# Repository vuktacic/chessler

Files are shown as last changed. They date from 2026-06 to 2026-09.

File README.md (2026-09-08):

# chessler/chessbot
A robot that plays chess. It uses a camera to detect Aruco tags on the board corners and the pieces, and an electromagnet on a gantry under the board to move the pieces. Designed for Hack Club's Outpost program. I wanted to do something involving Aruco tags outside of FRC, and this seemed like a good project to make.

## Structure
- [./assets](./assets): Repo images
- [./cad](./cad): 3d models
- [./core](./core): esp32 firmware
- [./pcb](./pcb): Kicad design files.
- [./vision](./vision): Computer side vision code
- [./bom.csv](./bom.csv): Bill of materials
- [./po.csv](./po.csv): Purchase order
- [./JOURNAL.md](./JOURNAL.md): Project journal

View the PCB on KiCanvas:  


## CAD





## Schematic

Schematic

## PCB
PCB front
PCB back
PCB assembly
PCB detail

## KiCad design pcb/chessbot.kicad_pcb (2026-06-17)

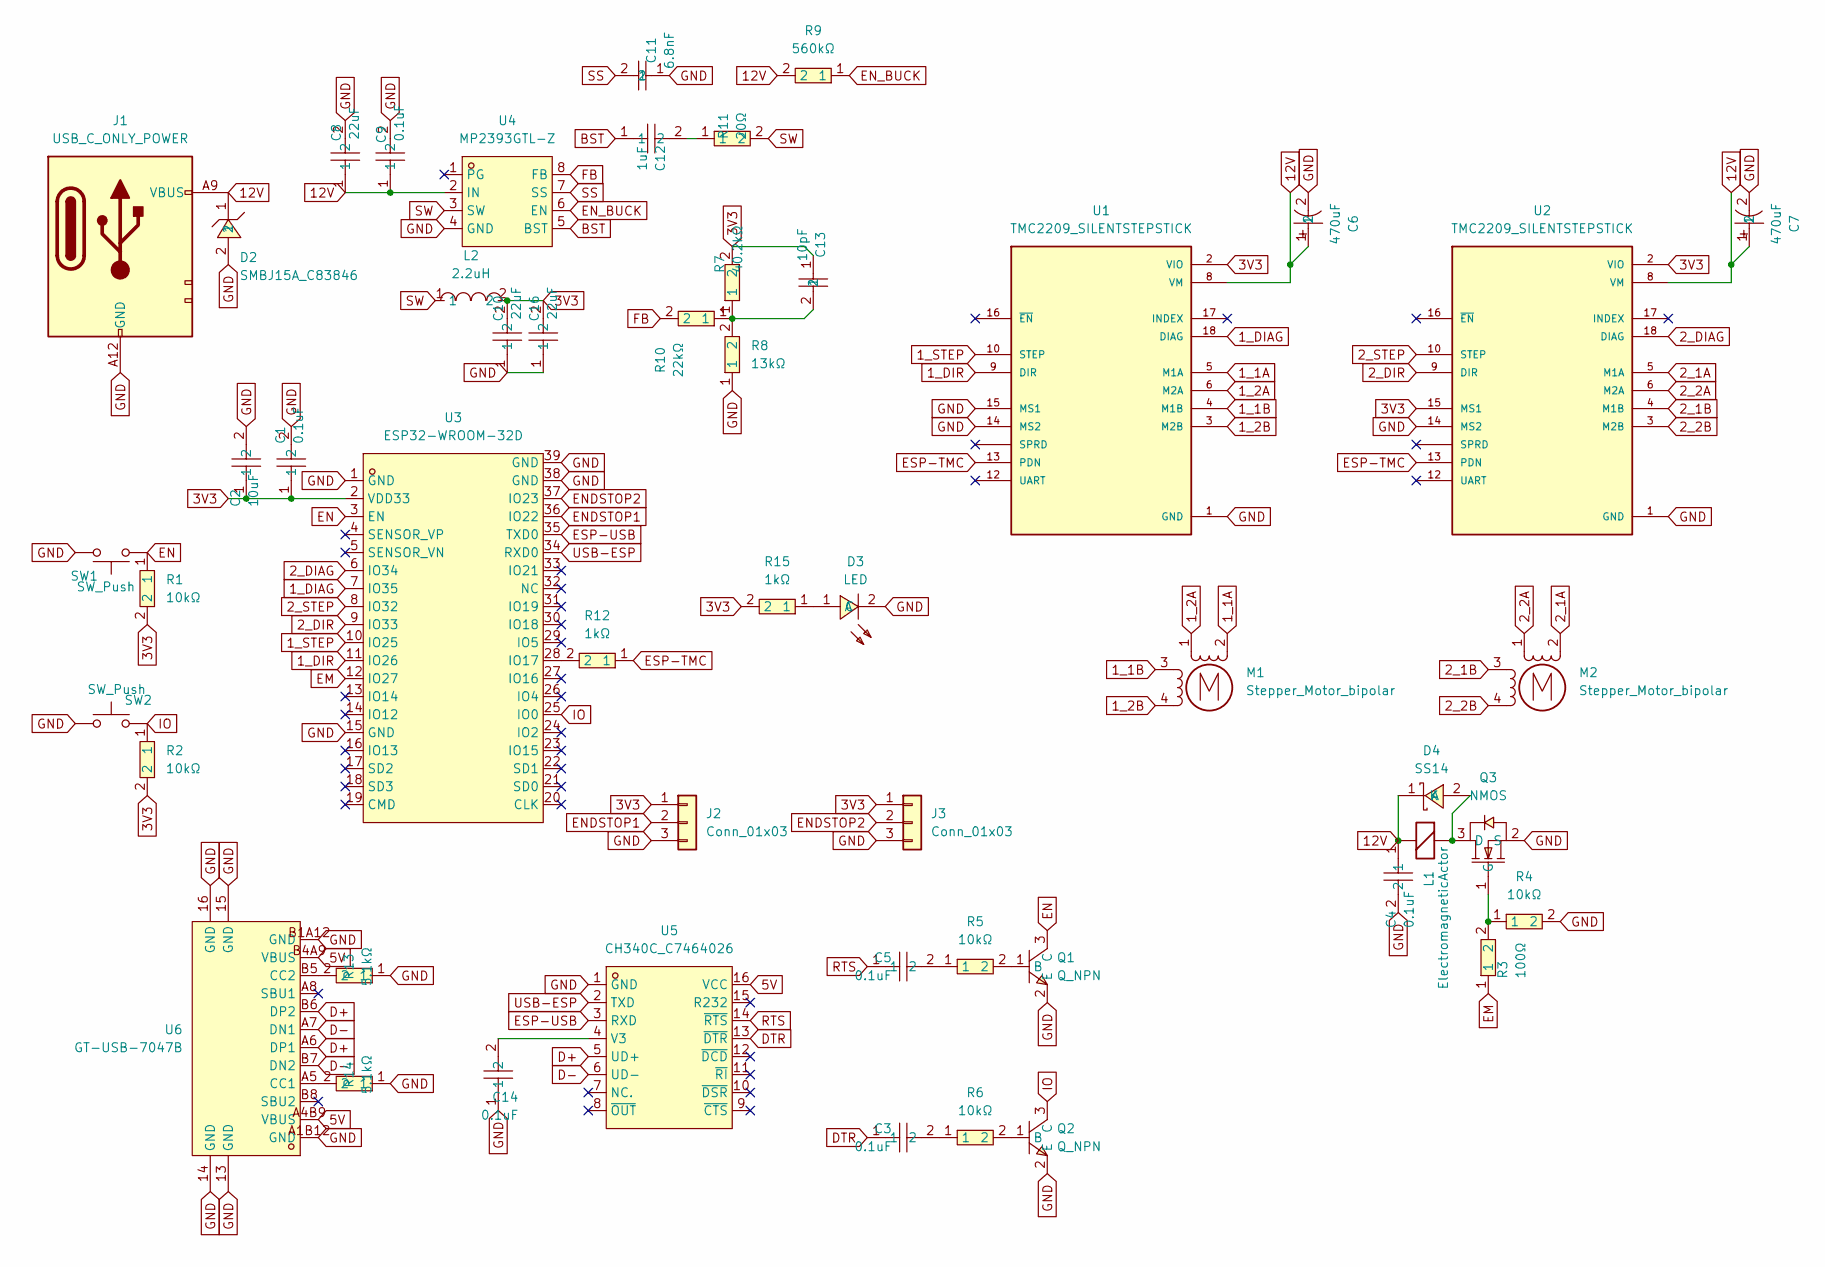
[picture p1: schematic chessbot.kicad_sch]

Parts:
C1, C3, C4, C5, C9, C14: 0.1uF; C0603; MPN CC0603KRX7R9BB104; LCSC Part C14663
C2: 10uF; C0603; MPN CL10A106MA8NRNC; LCSC Part C96446
C6, C7: 470uF; CAP-SMD_BD10.0-L10.3-W10.3-FD; MPN RVT1V471M1010; LCSC Part C3350
C8, C10, C16: 22uF; C0805; MPN CL21A226MAQNNNE; LCSC Part C45783
C11: 6.8nF; C0603; MPN 0603B682K500NT; LCSC Part C1631
C12: 1uF; C0603; MPN CL10A105KB8NNNC; LCSC Part C15849
C13: 10pF; C0603; MPN CL10C100JB8NNNC; LCSC Part C1634
D2: SMBJ15A_C83846; SMB_L4.6-W3.6-LS5.3-RD; LCSC Part C83846
D3: LED; LED0603-R-RD_AMBER; MPN BL-HJC36G-AV-TRB; LCSC Part C165983
D4: SS14; SMA_L4.2-W2.6-LS5.0-RD_1; MPN SS14; LCSC Part C2480
J1: USB_C_ONLY_POWER; USB_C_PD_BOARD
J2, J3: Conn_01x03; JST_PH_B3B-PH-K_1x03_P2.00mm_Vertical
L1: ElectromagneticActor; JST_PH_B2B-PH-K_1x02_P2.00mm_Vertical
L2: 2.2uH; L0805; MPN CMI201209U2R2KT; LCSC Part C1043
M1, M2: Stepper_Motor_bipolar; JST_PH_B4B-PH-K_1x04_P2.00mm_Vertical
Q1, Q2: Q_NPN; SOT-23-3_L2.9-W1.3-P1.90-LS2.4-BR; MPN MMBT3904(RANGE:100-300); LCSC Part C20526
Q3: NMOS; SOT-23-3_L2.9-W1.3-P1.90-LS2.4-BR; MPN AO3400A; LCSC Part C20917
R1, R2, R4, R5, R6: 10kΩ; R0805; MPN 0805W8F1002T5E; LCSC Part C17414
R3: 100Ω; R0603; MPN 0603WAF1000T5E; LCSC Part C22775
R7: 40.2kΩ; R0603; MPN 0603WAF4022T5E; LCSC Part C12447
R8: 13kΩ; R0603; MPN 0603WAF1302T5E; LCSC Part C22797
R9: 560kΩ; R0603; MPN 0603WAF5603T5E; LCSC Part C23203
R10: 22kΩ; R0603; MPN 0603WAF2202T5E; LCSC Part C31850
R11: 20Ω; R0603; MPN 0603WAF200JT5E; LCSC Part C22950
R12, R15: 1kΩ; R0603; MPN 0603WAF1001T5E; LCSC Part C21190
R13, R14: 5.1kΩ; R0603; MPN 0603WAF5101T5E; LCSC Part C23186
SW1, SW2: SW_Push; SW_PUSH_6mm
U1, U2: TMC2209_SILENTSTEPSTICK; MODULE_TMC2209_SILENTSTEPSTICK_INTERNAL SILKSCREEN; PARTREV 1.20
U3: ESP32-WROOM-32D; WIFIM-SMD_39P-L25.5-W18.0-P1.27-BL; MPN ESP32-WROOM-32D-N4; LCSC Part C529578
U4: MP2393GTL-Z; SOT-583-8_L2.1-W1.2-P0.50-LS1.6-BL; MPN MP2393GTL-Z; LCSC Part C6674609
U5: CH340C_C7464026; SOP-16_L10.0-W3.9-P1.27-LS6.0-BL; MPN CH340C; LCSC Part C7464026
U6: GT-USB-7047B; MICRO-USB-SMD_GT-USB-7047B; MPN GT-USB-7047B; LCSC Part C963217

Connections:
1_1A: M1.2 (-_2), U1.5 (M1A)
1_1B: M1.3, U1.4 (M1B)
1_2A: M1.1, U1.6 (M2A)
1_2B: M1.4, U1.3 (M2B)
1_DIAG: U1.18 (DIAG), U3.7 (IO35)
1_DIR: U1.9 (DIR), U3.11 (IO26)
1_STEP: U1.10 (STEP), U3.10 (IO25)
2_1A: M2.2 (-_2), U2.5 (M1A)
2_1B: M2.3, U2.4 (M1B)
2_2A: M2.1, U2.6 (M2A)
2_2B: M2.4, U2.3 (M2B)
2_DIAG: U2.18 (DIAG), U3.6 (IO34)
2_DIR: U2.9 (DIR), U3.9 (IO33)
2_STEP: U2.10 (STEP), U3.8 (IO32)
3V3: C1.1, C2.1, C10.2, C13.1, C16.2, J2.1, J3.1, L2.2, R1.2, R2.2, R7.2, R15.2, U1.2 (VIO), U2.2 (VIO), U2.15 (MS1), U3.2 (VDD33)
5V: U5.16 (VCC), U6.A4B9 (VBUS), U6.B4A9 (VBUS)
12V: C4.1, C6.1, C7.1, C8.1, C9.1, D2.1, D4.1 (K), J1.A9 (VBUS), L1.2 (+), R9.2, U1.8 (VM), U2.8 (VM), U4.2 (IN)
BST: C12.1, U4.5 (BST)
D+: U5.5 (UD+), U6.A6 (DP1), U6.B6 (DP2)
D-: U5.6 (UD-), U6.A7 (DN1), U6.B7 (DN2)
DTR: C3.1, U5.13 (~DTR)
EM: R3.1, U3.12 (IO27)
EN: Q1.3 (C), R1.1, SW1.1, U3.3 (EN)
ENDSTOP1: J2.2, U3.36 (IO22)
ENDSTOP2: J3.2, U3.37 (IO23)
EN_BUCK: R9.1, U4.6 (EN)
EN_TMC: U1.16 (~EN), U2.16 (~EN)
ESP-TMC: R12.1, U1.13 (PDN), U2.13 (PDN)
ESP-USB: U3.35 (TXD0), U5.3 (RXD)
FB: R10.2, U4.8 (FB)
GND: C1.2, C2.2, C4.2, C6.2, C7.2, C8.2, C9.2, C10.1, C11.1, C14.1, C16.1, D2.2, D3.2 (C), J1.A12 (GND), J2.3, J3.3, Q1.2 (E), Q2.2 (E), Q3.2 (S), R4.2, R8.1, R13.1, R14.1, SW1.2, SW2.1, U1.1 (GND), U1.7 (GND), U1.14 (MS2), U1.15 (MS1), U2.1 (GND), U2.7 (GND), U2.14 (MS2), U3.1 (GND), U3.15 (GND), U3.38 (GND), U3.39 (GND), U4.4 (GND), U5.1 (GND), U6.13 (GND), U6.14 (GND), U6.15 (GND), U6.16 (GND), U6.A1B12 (GND), U6.B1A12 (GND)
IO: Q2.3 (C), R2.1, SW2.2, U3.25 (IO0)
unnamed: C3.2, R6.1
unnamed: C5.2, R5.1
unnamed: C12.2, R11.1
unnamed: C13.2, R7.1, R8.2, R10.1
unnamed: D3.1 (A), R15.1
unnamed: D4.2 (A), L1.1 (-), Q3.3 (D)
unnamed: Q1.1 (B), R5.2
unnamed: Q2.1 (B), R6.2
unnamed: Q3.1 (G), R3.2, R4.1
unnamed: R12.2, U3.28 (IO17)
unnamed: C14.2, U5.4 (V3)
unnamed: R14.2, U6.A5 (CC1)
unnamed: R13.2, U6.B5 (CC2)
RTS: C5.1, U5.14 (~RTS)
SS: C11.2, U4.7 (SS)
SW: L2.1, R11.2, U4.3 (SW)
USB-ESP: U3.34 (RXD0), U5.2 (TXD)

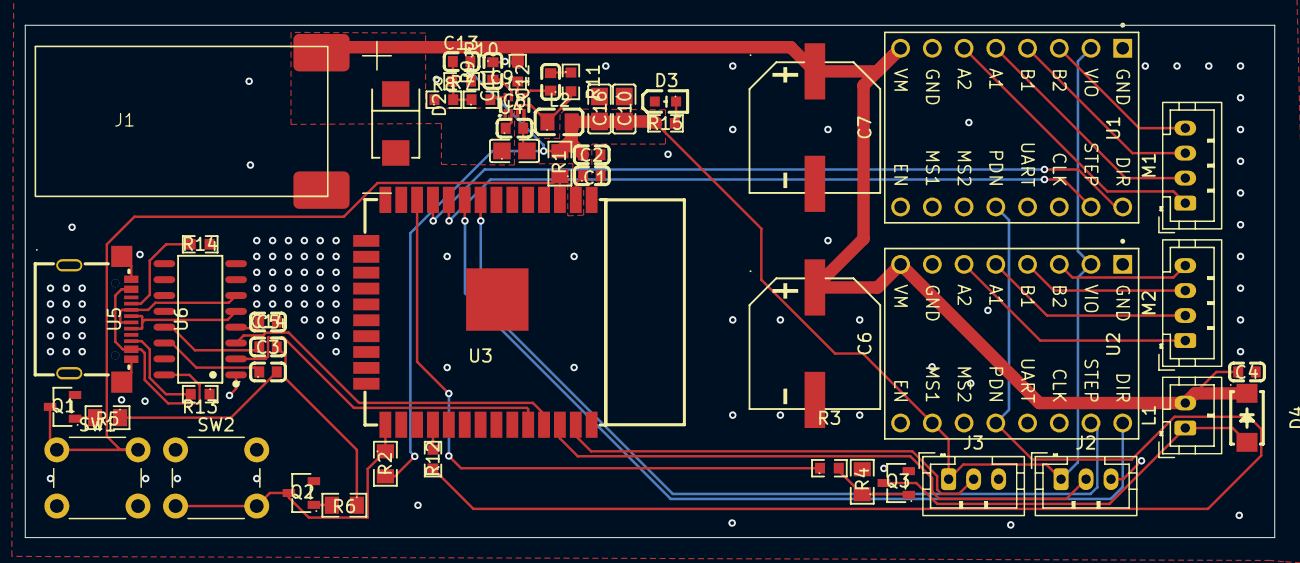
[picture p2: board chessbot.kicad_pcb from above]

Board: 2 copper layers, 100.0 x 41.0 mm, 51 parts (0 on the bottom side), 47 nets.

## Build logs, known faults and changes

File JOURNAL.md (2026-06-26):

# chessler Journal

## June 13th, 2026
New project time!
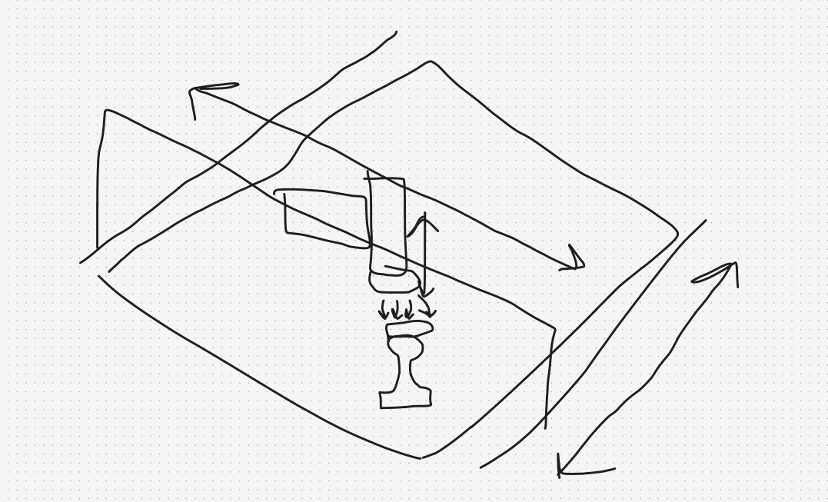
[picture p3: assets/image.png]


I've been thinking about this one for a couple days. It's a chess playing robot. My original idea was to have a gantry, but after deliberation I realized that an under the board design would be more compact, cleaner, and cheaper.

I would use a camera to detect the pieces. Object detection can be quite hard, but I realized that I can just attach pieces of coloured paper to the tops of the pieces, and then just use colour detection to find the pieces.

I started sourcing parts from aliexpress.
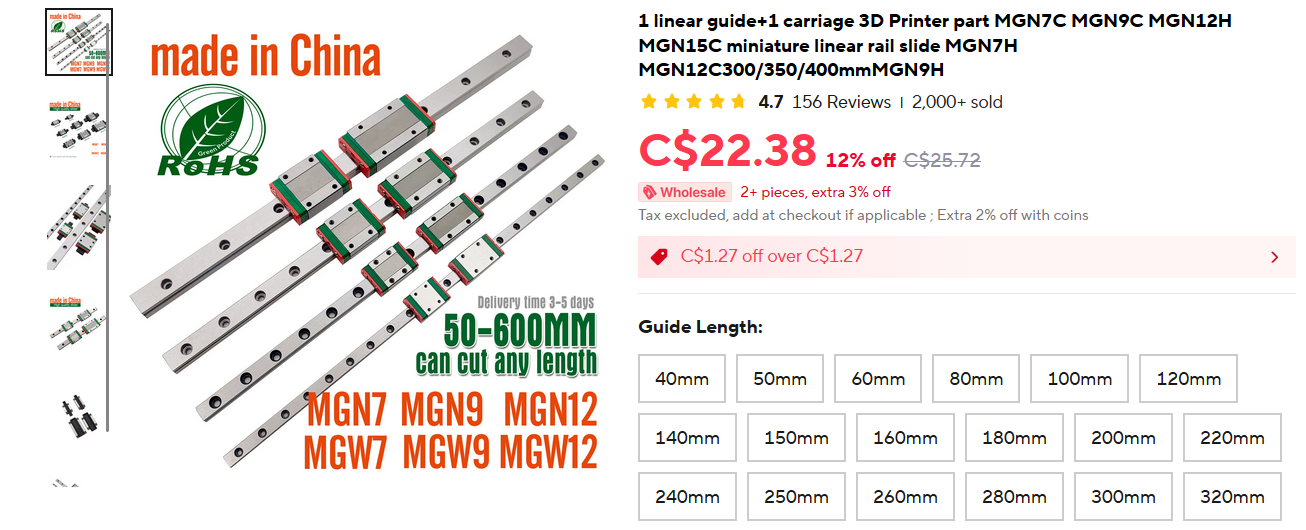
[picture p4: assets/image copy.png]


I'm using MGN12 rails, which use M3 hardware which I already have.

I also found a nice tiny electromagnet:
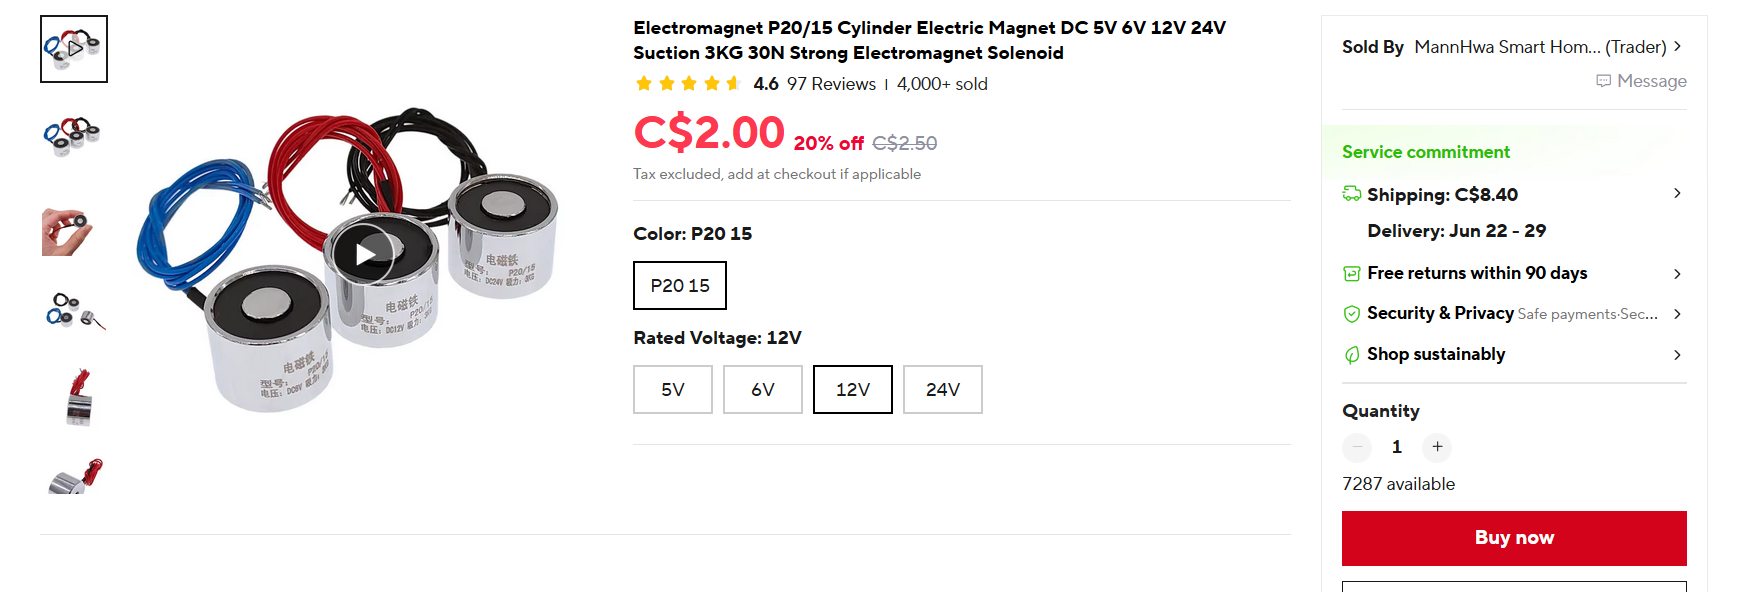
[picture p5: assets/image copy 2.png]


It's 20mm wide and 15mm thick with 30N of holding force.

About the magnet, I needed to make sure that it would be strong enough to drag pieces, but not so strong that it would pick up pieces unintendedly. (Picking up *A* piece is way easier than picking up *ONE* piece). I did some back of the napkin calculations and found that magnetic force generally dissipiates by 1/r^4. Meaning that the force of the electromagnet on side pieces is <1% of the force of a centered piece. (Assuming 6mm thick MDF and 45mm center to center piece distance).

I picked up some other things, like a bigger Nema 17 motor, M3 t-nuts, M5 brackets, extrusion, and optical endstops.
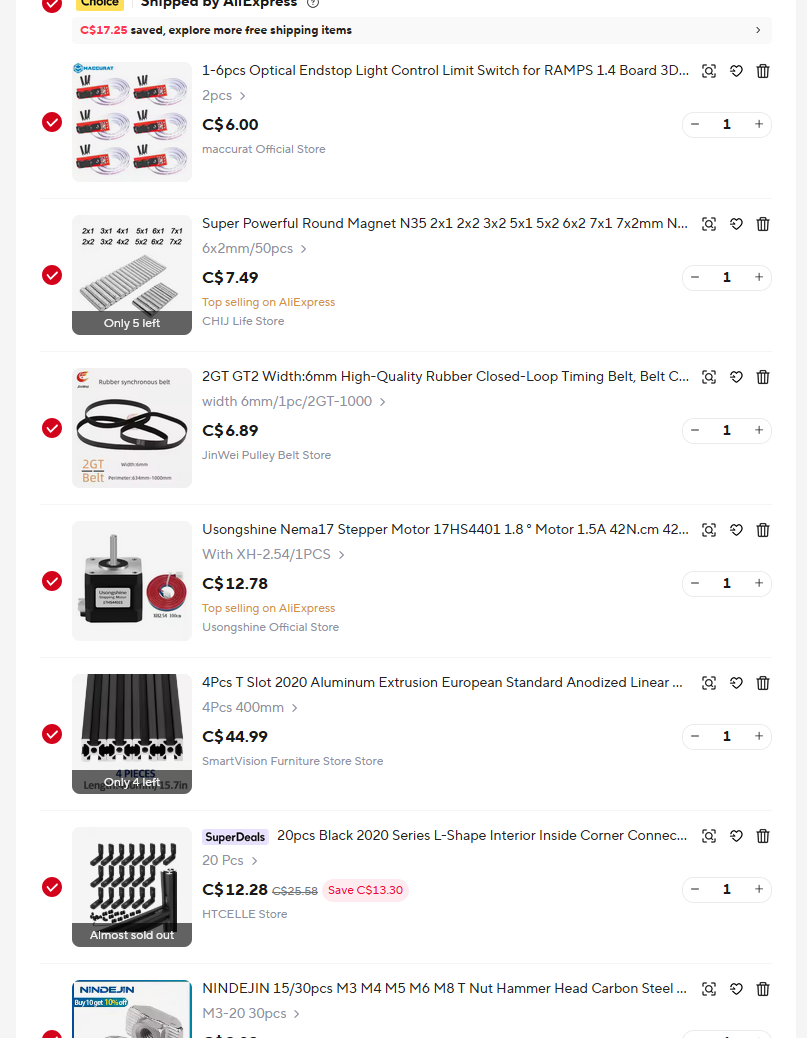
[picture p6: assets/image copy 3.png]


I then hopped into fusion and started designing this.

Funny thing, I actually have quite a lot of experience designing with Aluminum extrusion. I did it all the time for FRC, and man I hated it. I really thought I escaped it!

However, when you can actually source proper components for it, it's pretty nice!

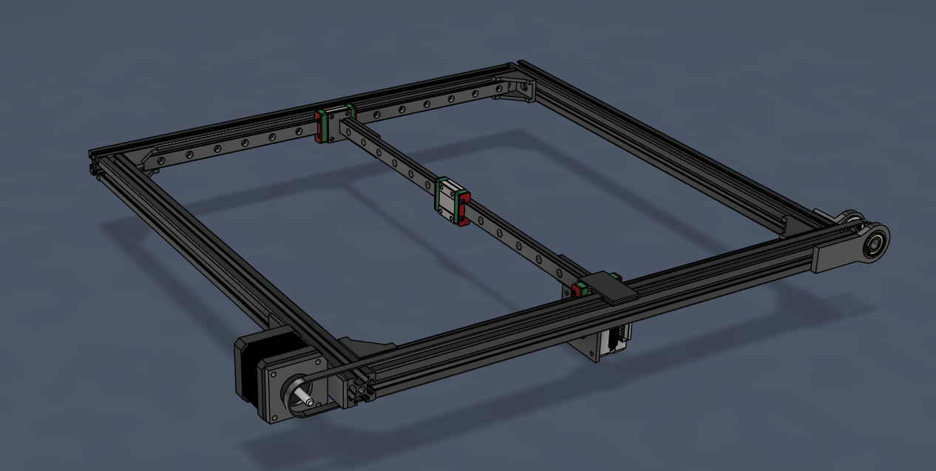
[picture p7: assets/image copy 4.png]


I made the X axis belt run over the side extrusion, and started designing the gantry to hold the motor and clamp onto the belt. Lowkey, I don't really anticipate this taking too much time—most of it was spent sourcing parts. Tomorrow I'll have a lot of time to cad out the rest of the project, and then refine the tiny details and total the parts. After that, I'll start making the PCB for it.

Time today: 4.0 hours  
**Time total: 4.0 hours**  

## June 14th, 2026

Locked in so hard today. I went to the library and spent around a half hour looking at components on aliexpress. I realized that I didn't need optical endstops because I already had leftovers. I then hopped into fusion and continued designing.



I designed the actually chessboard, and then refined some of the parts.

I added the pulleys:


and the bolt counterbores:




I also designed the pulley holder for the gantry.



Funny story on this one, I actually originally designed it to bolt directly to the extrusion. So... it wouldn't be able to slide with the rest of the gantry. I had to redesign it to mount directly to the plate, and then redesign it AGAIN so that it wouldn't interfere with the carriage.

I then fleshed out the belt clamp for the gantry:



and one for the carriage:



I then modelled the electromagnet and mounted it to the carriage:



I had a couple problems with the carriage. Namely, it interfered with the pulley holder (so I had to redesign it), and I had to shift the Nema motor back to allow for the carriage to get close to the edges.

I then added the texture to the chessboard:


I then joined it so that the electromagnet at it's bounds were under the center of each corner square, and created mounts to connect it to the extrusion




I still have work to do in fusion, namely filleting and legs for the extrusion frame.

I'm currently debating what to make the board out of. 1/4" MDF was my original plan, but acrylic would be pretty sick because you can look through it to see the electromagnet moving (also makes integration and debugging easier!).

After I got home from the library, I sat down and worked on the kicad schematic.

This is my first time putting actual chips on the pcb, instead of using sockets, so I had to do a lot of research on that.

I picked up an esp32 wroom chip with flash (to run a shitty stockfish later), a usb-uart bridge, a usb c port, and a buck converter.






I then started learning how to wire it up.

First I did the usb c port with its 5.1kΩ resistors, and then hooked it up the CH340C usb-uart bridge.

I then connected the bridge like it said to in the datasheet, and then set up the RTS and DTR pins to be able to reset the esp32 while programming.

I had a hiccup here, the only datasheet I could find (the one on JLC) was in chinese, so I had to translate the entire document and use the scuffed misaligned translation to figure out pin purposes.



I then set up the electromagnet. It's not a super beefy one, 12V @ 0.13A, so I don't need to worry too much about heat dissipation. I set up the mosfet to be controlled by the esp32, and then added a flyback diode to protect from the electromagnet dumping voltage back into the circuit.



I hooked up the tmc2209s. Last time I used pure UART control, which was pretty neat, but kinda hard to find a library. It also doesn't allow for more complex motion profiles (which this project would benefit from). So I decided to use UART for configuration, and then the usual step/dir for motion control via bit banging.



I then set up the power supply and buck converter. This was honestly the hardest part because I've never done anything like this before (I usually just used a buck breakout board).

I followed the datasheet and set correct values and routing. So, decoupling capacitors, the voltage divider (with their chosen resistors), the inductor (which I have never used before), and the switching pins. There's a lot of weird component values here like a 10pF capacitor on feedback and a 7nF capacitor on SS, but I matched the datasheet so I hope it works!



Here's the finished schematic! Honestly the most complex electrical thing I've ever done, and I'm proud of it. I still have to pick the components from JLC, but I think I have a good idea of what I want (0603 passives & x(5/7)r ceramic capacitors). After that's done, I can start the PCB layout and routing!



Time today: 9.0 hours  
**Time total: 13.0 hours**  

## June 15th, 2026

Today I wrapped up the schematic and part sourcing for the PCB.

The first thing I did was add the endstops to the schematic.


I sourced all the parts for my inductor, resistors, capacitors, transistors, and my mosfet. I made sure to use basic or promotional extended for all of my parts, and then tried to use 0603 whereever I could.

I then went through and swapped up the schematic symbols with JLC symbols from easyeda2kicad. This was pretty shitty because literally all of the symbols were rotated 90deg from the standard kicad symbols, AND were 1 unit longer.

I then assigned all of my footprints and loaded everything into PCBNEW.


(it's looking to be a pretty complex board!)

I exported my bom and loaded it into JLC.



It took a bit of finagling (I didn't check basic/extended status for some parts), but I got it down to $50usd for pcba and shipping!

I have some passives left over from previous projects, so I can avoid extended parts and just hand solder them in.

There were also a couple issues. I.e. the transistors, mosfet, and the usb-uart bridge were all rotated wrong in translation. I'll need to go through the kicad jlc plugin docs to figure out how to rectify that.

Other than that, it's going pretty great!

Time today: 3.5 hours  
**Time total: 16.5 hours**  

## June 16th, 2026

Today I routed the PCB!

However before I could do that, there was an issue I needed to fix.

I had to change this from GND to SW (don't know how I missed that one!)



THen I started placing all my components. I planned for a very compact board of 100mm x 40mm, so it was truly cramped.



I made sure to keep my usb C port away and separate from the noisy buck converter and tmc drivers. I placed the esp32 chip in the middle, and then the connectors and drivers at the end.

I then got to work routing it.



This is the most complex board I've made so far, and it was a fun challenge to route it on only 2 layers. I was able to keep all of the usb logic on the top layer, and most of the buck converter as well. I had to run long bottom layer traces for the tmc2209 step, uart, and dir pins. I'm not happy about the 3V3 injection cuting off nearly the entire back 5mm of the board, but it is what it is.

I made sure to use pours for the buck converter to ensure proper dissipation, and then filled the ground plane with stiching vias to ensure low resistance and connection.

I still need to fix up the mess of a silkscreen it is right now, but other than that, it's pretty much done.

Overall, I'm pretty happy with how it turned out! I need to plug it into JLC as a final check for manufacturability, but I don't anticipate any issues. I also want to get a review by someone (either on the slack or on reddit) just to be sure I didn't miss anything.






Time today: 4.5 hours  
**Time total: 21.0 hours**  

## June 17th, 2026

So, a lot got done today. First of all, I got the chess board etched! I switched from wood to tinted acrylic. Acrylic because you can see through it and see the gantry moving, and tinted for hype moments and aura.




So after I packed that in my backpack, I got to work on finishing the CAD.

I created an enclosure + acrylic cover for the PCB.



I then created tabs for the corner Aruco markers.





I then found the EXACT 3d model of the usb camera I'm using on grabcad, and created this goofy looking cone to determine the fov. I don't actually have the specs for that, but I assumed 120deg because people in the reviews said it had a wide fov.



I then spent way too long making this laser cut jig to determine the camera height. Yes it looks like shit. IT WILL BE REPLACED LATER. When I determine the correct height I'll 3d print a stand that goes to the correct location.


I then added counterbore spacings to everything:


And legs to allow space for the bottom gantry:


I did have to shift over the legs on the other side to allow clearance for the gantry motor that will be moving back and forth (the x-axis),

Then came the "polishing" (read: mass filleting).




After that, I added fasteners to everything. Once again, I'm standardizing around M3 bolts. I will have to use an extra M4 to mount the electromagnet. There will actually be quite a lot of fasteners on the robot though. A good 40 or so M3x6's, and a good 50 M3-20 t-nuts.

Either way, excited to be finished with the board cad. I still need to create the pieces. I'll probably rip a free to use model from grabcad, and modify it so that the pieces have spaces on the bottom for magnets and a "hat" on the top for an aruco marker. After that's done, I'll need to start working on the esp32 firmware (easy), and the aruco computer vision (very hard).

Time today: 5.0 hours  
**Time total: 26.0 hours**

## June 23rd, 2026

Came back from Nexus! Chill event and was happy to see SF once more. Either way, I'm super sleep deprived and trying to catchup from ym all-nighter on Sat-Sun. I found some nice chess pieces from grabcad with an open license, and then imported them into fusion. I then scaled them down to be 0.75" in diameter (19.05mm). I then created a 20mmx20mmx2mm platform for the Aruco tag exactly 2" above the board on each piece. (I used a post to standardize the diameters.)

I then filleted everything to ensure printing with minimal supports!



Time today: 1.0 hours
**Time total: 27.0 hours**

## June 24th, 2026

I added magnet holes for all the pieces. I found some nice 6x2 neodymium magnets on aliexpress.



I created a 6.4mmx2.2mm hole in the bottom of each piece to fit said magnets. There are 32 pieces in total, so I'll need to get the 50 pack of magnets.



I have black filament at home, but I can contract a friend to print white version of all the pieces.

It's going to take a lot of print time (currently 15 hours), but I think I can shave off a ton of time by removing unneeded supports (my printer can do 80deg overhangs, and many of the supports are supporting 50-60deg overhangs.)

With that, the CAD is done! Woohoo! Now I need to do the firmware. Yikes.

Time today: 1.0 hours  
**Time total: 28.0 hours**

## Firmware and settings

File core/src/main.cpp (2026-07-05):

#include <Arduino.h>
#include "sensors.h"
#include "relay.h"
#include "motion.h"
#include "chess.h"
#include <mcu-max.h>

static char pieceToFenChar(uint8_t piece) {
    switch (piece) {
        case 1:
        case 2:
            return 'P';
        case 3:
            return 'N';
        case 4:
            return 'K';
        case 5:
            return 'B';
        case 6:
            return 'R';
        case 7:
            return 'Q';
        case 9:
        case 10:
            return 'p';
        case 11:
            return 'n';
        case 12:
            return 'k';
        case 13:
            return 'b';
        case 14:
            return 'r';
        case 15:
            return 'q';
        default:
            return 0;
    }
}

static String boardToFen() {
    String fen;

    for (uint8_t row = 0; row < 8; row++) {
        uint8_t emptySquares = 0;

        for (uint8_t col = 0; col < 8; col++) {
            uint8_t piece = mcumax_get_piece(0x10 * row + col);
            char fenChar = pieceToFenChar(piece);

            if (!fenChar) {
                emptySquares++;
                continue;
            }

            if (emptySquares > 0) {
                fen += String(emptySquares);
                emptySquares = 0;
            }

            fen += fenChar;
        }

        if (emptySquares > 0) {
            fen += String(emptySquares);
        }

        if (row < 7) {
            fen += '/';
        }
    }

    fen += ' ';
    fen += (mcumax_get_current_side() == 0x8) ? 'w' : 'b';
    fen += " - - 0 1";

    return fen;
}

void setup() {
    sensors::init();
    relay::connect();
    motion::init();
    motion::home();
    
    // wait for pc message
    while(true) {
        if(Serial.available()) {
            String line = Serial.readStringUntil('\n');
            if(line == "pc_start") {
                Serial.println("esp_ack");
                break;
            }
        }
    }
}

void loop() {
    static bool waitingForVerification = false;
    static String expectedFen;

    // wait until next move from pc serial
    while(true) {
        String instruction = "";

        if(Serial.available()) {
            instruction = Serial.readStringUntil('\n');
        }

        if(instruction.startsWith("FEN")) {
            String fen = instruction.substring(4);
            fen.trim();

            if (waitingForVerification) {
                if (expectedFen == fen) {
                    Serial.println("esp_verify_ok");
                } else {
                    Serial.println("esp_verify_mismatch");
                    chess::setBoard(fen);
                    expectedFen = fen;
                }

                waitingForVerification = false;
                continue;
            }

            Serial.println("esp_ack fen");
            chess::setBoard(fen);
            chess::Move move = chess::bestMove();

            // if capture, move piece out of way first
            if(move.isCapture) {
                motion::moveTo(move.xf, move.yf, 0, 0, false);
                motion::pickUp();
                motion::moveTo(move.xf, move.yf, 0, 0, true);
                motion::drop();
            }

            motion::moveTo(move.xi, move.yi, 0, 0, false);
            motion::pickUp();
            motion::moveTo(move, true);
            motion::drop();

            expectedFen = boardToFen();
            waitingForVerification = true;
        }
    }
}

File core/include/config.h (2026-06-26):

#pragma once

#define Y_ENDSTOP 17
#define X_ENDSTOP 18

#define TMC_TX 16
#define TMC_EN 15
#define X_STEP 21
#define X_DIR 22
#define Y_STEP 19
#define Y_DIR 20

#define EM_PIN 14

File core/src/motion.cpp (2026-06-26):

#include <Arduino.h>
#include "motion.h"
#include "config.h"
#include <TMCStepper.h>
#include <FastAccelStepper.h>
#include "sensors.h"
#include "chess.h"

namespace motion {
    class Electromagnet {
    private:
        uint8_t pin;

    public:
        Electromagnet(uint8_t pin) {
            this->pin = pin;
            ledcSetup(0, 5000, 10);
            ledcAttachPin(pin, 0);
        }

        void setPower(uint8_t power) {
            ledcWrite(0, (power * 1023) / 100);
        }

    };

    // ms1 ms2 -> gnd & gnd then 3v3 & gnd for uart ids
    TMC2209Stepper xstepConfig(&Serial1, 0.11f, 0x00);
    TMC2209Stepper ystepConfig(&Serial1, 0.11f, 0x01);
    FastAccelStepperEngine engine = FastAccelStepperEngine();
    FastAccelStepper* xstepper = NULL;
    FastAccelStepper* ystepper = NULL;

    Electromagnet electromagnet(EM_PIN);

    int32_t mmToSteps(float mm) {
        // calculate based off of gt2 pulley with 20 teeth and 2mm pitch
        return (int32_t)(mm * 200 * 16 / (20 * 2));
    }

    void init() {
        pinMode(TMC_EN, OUTPUT);
        pinMode(X_STEP, OUTPUT);
        pinMode(X_DIR, OUTPUT);
        pinMode(Y_STEP, OUTPUT);
        pinMode(Y_DIR, OUTPUT);
        digitalWrite(TMC_EN, LOW);

        xstepConfig.begin();
        ystepConfig.begin();

        xstepConfig.toff(5);
        ystepConfig.toff(5);

        xstepConfig.rms_current(600);
        ystepConfig.rms_current(600);

        xstepConfig.microsteps(16);
        ystepConfig.microsteps(16);

        xstepConfig.pwm_autoscale(true);

        engine.init();
        xstepper = engine.stepperConnectToPin(X_STEP);
        ystepper = engine.stepperConnectToPin(Y_STEP);

        if(xstepper && ystepper) {
            xstepper->setDirectionPin(X_DIR);
            xstepper->setEnablePin(TMC_EN);
            xstepper->setAutoEnable(true);

            ystepper->setDirectionPin(Y_DIR);
            ystepper->setEnablePin(TMC_EN);
            ystepper->setAutoEnable(true);

            xstepper->setSpeedInHz(1000);
            ystepper->setSpeedInHz(1000);

            xstepper->setAcceleration(100);
            ystepper->setAcceleration(100);
        }
    }

    void home() {
        xstepper->runForward();

        while(!sensors::getXEndstop()) {}

        xstepper->stopMove();
        xstepper->setCurrentPosition(0);



        ystepper->runForward();

        while(!sensors::getYEndstop()) {}

        ystepper->stopMove();
        ystepper->setCurrentPosition(0);
    }

    void moveTo(int32_t xi, int32_t yi, int32_t xf, int32_t yf, boolean threaded) {
        // xstepper->moveTo(x);
        // ystepper->moveTo(yf);

        if(!threaded) {
            xstepper->moveTo(mmToSteps(22.5f + (45.0f * xf)));
            ystepper->moveTo(mmToSteps(22.5f + (45.0f * yf)));

            while(xstepper->isRunning() || ystepper->isRunning()) {}
        }
        else {
            // xstepper->moveTo(mmToSteps(22.5f + (45.0f * x)));
            // ystepper->moveTo(mmToSteps(22.5f + (45.0f * yf)));
            float xadj = 22.5f;
            float yadj = 22.5f;
            if(xf > 4) xadj = -xadj;
            if(yf > 4) yadj = -yadj;

            // thread between ranks & files
            xstepper->moveTo(mmToSteps(22.5f + (45.0f * xi) + xadj));
            while(xstepper->isRunning()) {}
            ystepper->moveTo(mmToSteps(22.5f + (45.0f * yi) + yadj));
            while(ystepper->isRunning()) {}

            xstepper->moveTo(mmToSteps(22.5f + (45.0f * xf) - xadj));
            while(xstepper->isRunning()) {}
            ystepper->moveTo(mmToSteps(22.5f + (45.0f * yf) - yadj));
            while(ystepper->isRunning()) {}

            xstepper->moveTo(mmToSteps(22.5f + (45.0f * xf)));
            while(xstepper->isRunning()) {}
            ystepper->moveTo(mmToSteps(22.5f + (45.0f * yf)));
            while(ystepper->isRunning()) {}
        }
    }

    void moveTo(const chess::Move& move, boolean threaded) {
        moveTo(move.xi, move.yi, move.xf, move.yf, threaded);
    }

    void pickUp() {
        electromagnet.setPower(100);
        delay(250);
        electromagnet.setPower(50);
    }

    void drop() {
        electromagnet.setPower(0);
    }
}

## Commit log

2026-06-14 CAD begin
2026-06-15 Journalling for yesterday: fusion cad & kicad schematic
    [chessbot.kicad_pcb, chessbot.kicad_sch]
2026-06-15 Update kicad gitignore
2026-06-16 Journal for yesterday: jlc component sourcing
    [chessbot.kicad_pcb, chessbot.kicad_sch]
2026-06-17 PCB routing
    [chessbot.kicad_pcb, chessbot.kicad_sch]
2026-06-18 Major CAD progress
2026-06-25 Finish cad
2026-06-26 Most of the firmware & board fen from aruco tags
2026-07-05 Serial working + board check workflow
